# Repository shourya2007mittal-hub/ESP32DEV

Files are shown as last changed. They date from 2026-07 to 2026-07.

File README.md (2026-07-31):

# ESP32DEV



I made a custom Devboard based on ESP32-S3-WROOM-1 . It has voltage regulator , LED indicators , Boot Pin and the best part is that all the Pins available on the WROOM-1 is accessible via connector including BOOT, EN, DATA Lines.

## Features
- Base on  ESP32-S3-WROOM-1
- Has 3.3 V voltage regulator 
- All the possible WROOM-1 pins are accesible via pin connector

---

 | Top Designator | Comment | Footprint | Qty | Total Price (USD) | Product Link |
|:--------------|:--------|:----------|---:|------------------:|:-------------|
| C2 | 47uF | 0201 | 2 | $1.3330 | https://jlcpcb.com/partdetail/3127-KM476M450K25RR0VH2FP0/C2746 |
| C3 | 10uF | 0201 | 20 | $0.5860 | https://jlcpcb.com/partdetail/2043-CL10A106MQ8NNNC/C1691 |
| C4 | 100nF | 0201 | 20 | $0.1460 | https://jlcpcb.com/partdetail/MurataElectronics-GRM033R61A104KE15D/C76934 |
| C5, C6 | 22uF | 0201 | 8 | $2.5128 | https://jlcpcb.com/partdetail/2211-1206X226K100NT/C1859 |
| C5(1UF)1, C6(100NF)1 | C5(1UF)1, C6(100NF)1 | 0805 | 20 | $0.6440 | https://jlcpcb.com/partdetail/YAGEO-CC0805KRX7R9BB104/C49678 |
| D1, D2, D3 | LED | 0201 | 10 | $0.6810 | https://jlcpcb.com/partdetail/XINGLIGHT-XL0201SURC/C3646923 |
| D4 | 1N4001 | D_DO-41_SOD81_P2.54mm_Vertical_AnodeUp | 4 | $0.0776 | https://jlcpcb.com/partdetail/49200031-1N4001/C47018536 |
| L1 | 4.7uH | 0603 | 20 | $0.4140 | https://jlcpcb.com/partdetail/Sunlord-SDFL1608Q4R7KTF/C1034 |
| L2 | 2.2uH | 0603 | 20 | $0.5040 | https://jlcpcb.com/partdetail/270373-CMI160808U2R2KT/C284875 |
| Q1 | AO3401A | SOT-23 | 6 | $0.5946 | https://jlcpcb.com/partdetail/Alpha_OmegaSemicon-AO3401A/C15127 |
| R1, R2 | 33Ω | 0603 | 20 | $0.1580 | https://jlcpcb.com/partdetail/23867-0603WAF330JT5E/C23140 |
| R3, R4 | 50kΩ | 0603 | 20 | $0.6500 | https://jlcpcb.com/partdetail/YAGEO-RT0603BRD0750KL/C861451 |
| R6, R7, R8 | 1kΩ | 0201 | 20 | $0.0500 | https://jlcpcb.com/partdetail/259895-0201WMF1001TEE/C270365 |
| R1(10K)1, R2(100R)1 | R | 0805 | 6 | $0.5364 | https://jlcpcb.com/partdetail/FuzetecTech-FSMD050_0805R/C181350 |
| SW1, SW2 | Push Button | SW_SPST_PTS810 | 4 | $2.3948 | https://jlcpcb.com/partdetail/41719-DSHP02TSGET/C40735 |
| U5 | ESP32-S3-WROOM-1 | ESP32-S3-WROOM-1 | 2 | $10.8594 | https://jlcpcb.com/partdetail/3198300-ESP32_S3_WROOM_1N16R8/C2913202 |
| U2 | AP63203WU | TSOT-23-6 | 5 | $0.6019 | https://jlcpcb.com/partdetail/DiodesIncorporated-AP63203WU7/C780769 |
| PCB | PCB Fabrication | — | 1 | $4.00 | https://jlcpcb.com |
| SETUP | Assembly Setup Fee | — | 1 | $25.00 | https://jlcpcb.com |
| LOAD | Component Loading Fee | — | 1 | $14.00 | https://jlcpcb.com |
| SHIPPING | Shipping | — | 1 | $16.78 | https://jlcpcb.com |
| **TOTAL** | | | | **$82.5235** | https://jlcpcb.com |

### 💵 Cost Summary

| Item | Cost (USD) |
|---|---:|
| Components | $22.7435 |
| PCB Fabrication | $4.00 |
| Assembly Setup | $25.00 |
| Component Loading | $14.00 |
| Shipping | $16.78 |
| **Grand Total** | **$82.5235** |

### Schematic



###  PCB Design



### 3D Design



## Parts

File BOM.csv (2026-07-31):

Top Designator | Comment | Footprint | Quantity | Total Price | Product Link
C2 | 47uf | 0201 | 2.0 | 1.333 | https://jlcpcb.com/partdetail/3127-KM476M450K25RR0VH2FP0/C2746
C3 | 10uf | 0201 | 20.0 | 0.586 | https://jlcpcb.com/partdetail/2043-CL10A106MQ8NNNC/C1691
C4 | 100nf | 0201 | 20.0 | 0.146 | https://jlcpcb.com/partdetail/MurataElectronics-GRM033R61A104KE15D/C76934
C5,C6 | 22uf | 0201 | 8.0 | 2.5128 | https://jlcpcb.com/partdetail/2211-1206X226K100NT/C1859
C5(1UF)1,C6(100NF)1 | C5(1UF)1,C6(100NF)1 | 0805 | 20.0 | 0.644 | https://jlcpcb.com/partdetail/YAGEO-CC0805KRX7R9BB104/C49678
D1,D2,D3 | LED | 0201 | 10.0 | 0.681 | https://jlcpcb.com/partdetail/XINGLIGHT-XL0201SURC/C3646923
D4 | 1N4001 | D_DO-41_SOD81_P2.54mm_Vertical_AnodeUp | 4.0 | 0.0776 | https://jlcpcb.com/partdetail/49200031-1N4001/C47018536
L1 | 4.7uh | 0603 | 20.0 | 0.414 | https://jlcpcb.com/partdetail/Sunlord-SDFL1608Q4R7KTF/C1034
L2 | 2.2uh | 0603 | 20.0 | 0.504 | https://jlcpcb.com/partdetail/270373-CMI160808U2R2KT/C284875
Q1 | AO3401A | SOT-23 | 6.0 | 0.5946 | https://jlcpcb.com/partdetail/Alpha_OmegaSemicon-AO3401A/C15127
R1,R2 | 33R | 0603 | 20.0 | 0.158 | https://jlcpcb.com/partdetail/23867-0603WAF330JT5E/C23140
R3,R4 | 50K | 0603 | 20.0 | 0.65 | https://jlcpcb.com/partdetail/YAGEO-RT0603BRD0750KL/C861451
R6,R7,R8 | 1K | 0201 | 20.0 | 0.05 | https://jlcpcb.com/partdetail/259895-0201WMF1001TEE/C270365
R1(10K)1,R2(100R)1 | R | 0805 | 6.0 | 0.5364 | https://jlcpcb.com/partdetail/FuzetecTech-FSMD050_0805R/C181350
SW1,SW2 | SW_Push | SW_SPST_PTS810 | 4.0 | 2.3948 | https://jlcpcb.com/partdetail/41719-DSHP02TSGET/C40735
U5 | ESP32-S3-WROOM-1 | ESP32-S3-WROOM-1 | 2.0 | 10.8594 | https://jlcpcb.com/partdetail/3198300-ESP32_S3_WROOM_1N16R8/C2913202
U2 | AP63203WU | TSOT-23-6 | 5.0 | 0.6019 | https://jlcpcb.com/partdetail/DiodesIncorporated-AP63203WU7/C780769
PCB | PCB Cost |  | 1.0 | 4.0 | https://jlcpcb.com
SETUP | Setup Fee |  | 1.0 | 25.0 | https://jlcpcb.com
LOAD | Loading Fee |  | 1.0 | 14.0 | https://jlcpcb.com
SHIPPING | Shipping |  | 1.0 | 16.78 | https://jlcpcb.com
TOTAL |  |  |  | 82.5235 | https://jlcpcb.com

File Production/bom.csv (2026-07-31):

Designator | Footprint | Quantity | Value | LCSC Part #
C2 | 0201 | 1 | 47uf
C3 | 0201 | 1 | 10uf
C4 | 0201 | 1 | 100nf
C5, C6 | 0201 | 2 | 22uf
C5(1UF)1, C6(100NF)1 | 0805 | 2 | C
D1, D2, D3 | 0201 | 3 | LED
D4 | D_DO-41_SOD81_P2.54mm_Vertical_AnodeUp | 1 | 1N4001
F1 | 0201 | 1 | Polyfuse
J1 | USB_C_Receptacle_G-Switch_GT-USB-7010ASV | 1 | USB_C_Receptacle_USB2.0_16P
J2, J3 | PinHeader_1x18_P2.00mm_Vertical | 2 | Conn_01x18_Pin
J5 | PinHeader_1x04_P1.00mm_Vertical | 1 | Conn_01x04_Pin
J6 | AMASS_XT30U-F_1x02_P5.0mm_Vertical | 1 | Conn_01x02_Pin
L1 | 0603 | 1 | 4.7uh
L2 | 0603 | 1 | 2.2uh
Q1 | SOT-23 | 1 | AO3401A
R1, R2 | 0603 | 2 | 33 R
R1(10K)1, R2(100R)1 | 0805 | 2 | R
R3, R4 | 0603 | 2 | 50K
R6, R7, R8 | 0201 | 3 | 1K
SW1, SW2 | SW_SPST_PTS810 | 2 | SW_Push
U2 | TSOT-23-6 | 1 | AP63203WU
U5 | ESP32-S3-WROOM-1 | 1 | ESP32-S3-WROOM-1

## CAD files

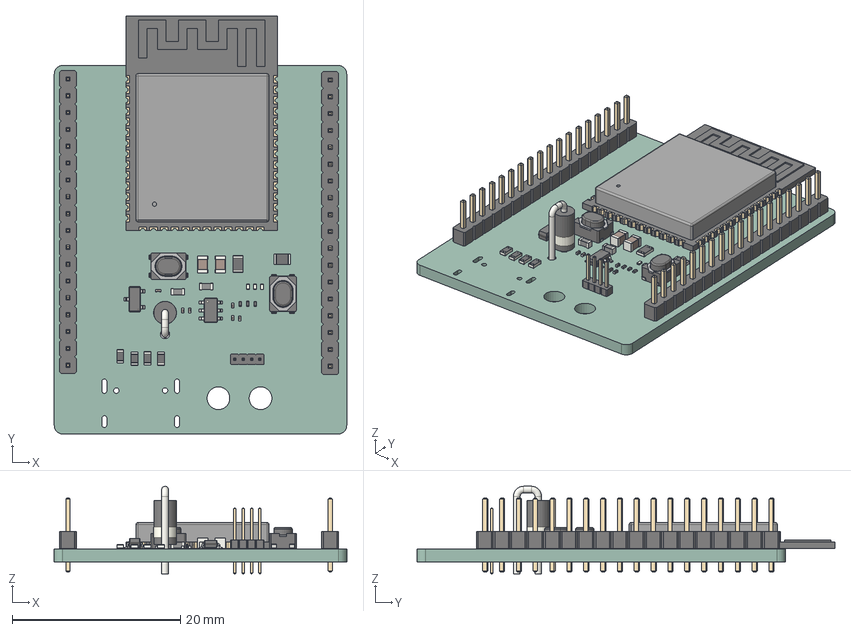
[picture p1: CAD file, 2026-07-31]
CAD/ESP32DEV.step
34.7 x 49.6 x 10.4 mm
C_0805_2012Metric x 2
PinHeader_1x18_P2.00mm_Vertical x 2
R_0805_2012Metric x 2
R_0201_0603Metric x 3
C_0201_0603Metric x 6
R_0603_1608Metric x 4
TSOT-23-6
SOT-23
SW_SPST_PTS810 x 2
LED_0201_0603Metric x 3
ESP32-S3-WROOM-1
D_DO-41_SOD81_P2.54mm_Vertical_AnodeUp
PinHeader_1x04_P1.00mm_Vertical
L_0603_1608Metric x 2
ESP32DEV_PCB

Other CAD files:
CAD/ESP32DEV.f3d

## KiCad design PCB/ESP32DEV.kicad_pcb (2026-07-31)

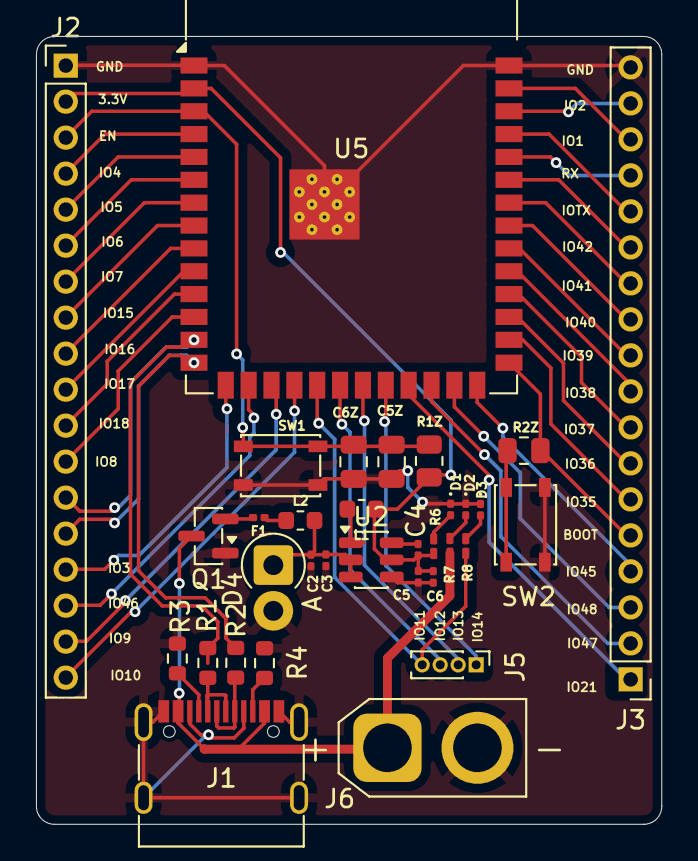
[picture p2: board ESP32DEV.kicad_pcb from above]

Board: 2 copper layers, 34.7 x 43.8 mm, 33 parts (0 on the bottom side), 53 nets.

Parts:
C2: 47uf; C_0201_0603Metric
C3: 10uf; C_0201_0603Metric
C4: 100nf; C_0201_0603Metric
C5, C6: 22uf; C_0201_0603Metric
C5Z, C6Z: C; C_0805_2012Metric
D1, D2, D3: LED; LED_0201_0603Metric
D4: 1N4001; D_DO-41_SOD81_P2.54mm_Vertical_AnodeUp
F1: Polyfuse; C_0201_0603Metric
J1: USB_C_Receptacle_USB2.0_16P; USB_C_Receptacle_G-Switch_GT-USB-7010ASV
J2, J3: Conn_01x18_Pin; PinHeader_1x18_P2.00mm_Vertical
J5: Conn_01x04_Pin; PinHeader_1x04_P1.00mm_Vertical
J6: Conn_01x02_Pin; AMASS_XT30U-F_1x02_P5.0mm_Vertical
L1: 4.7uh; L_0603_1608Metric
L2: 2.2uh; L_0603_1608Metric
Q1: AO3401A; SOT-23
R1, R2: 33 R; R_0603_1608Metric
R1Z, R2Z: R; R_0805_2012Metric
R3, R4: 50K; R_0603_1608Metric
R6, R7, R8: 1K; R_0201_0603Metric_Pad0.64x0.40mm_HandSolder
SW1, SW2: SW_Push; SW_SPST_PTS810
U2: AP63203WU; TSOT-23-6
U5: ESP32-S3-WROOM-1

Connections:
+3.3V: C4.1, C5.1, C6.1, J2.2, L1.1, R1Z.1, R6.1, U2.5 (SW), U5.2 (3V3)
+5V: J1.A4 (VBUS), J1.A9 (VBUS), J1.B4 (VBUS), J1.B9 (VBUS), J6.1, Q1.3 (D), R7.2
BOOT: J3.5, R2Z.1, U5.27 (IO0)
EN: C5Z.1, C6Z.1, J2.3, R1Z.2, SW1.1, U5.3 (EN)
GND: C2.2, C3.2, C5.2, C5Z.2, C6.2, C6Z.2, D1.1 (K), D2.1 (K), D3.1 (K), D4.2 (A), J1.A1 (GND), J1.A8 (SBU1), J1.A12 (GND), J1.B1 (GND), J1.B8 (SBU2), J1.B12 (GND), J1.S1 (SHIELD), J2.1, J3.18, J6.2, Q1.1 (G), R3.2, R4.2, SW1.2, SW2.2, U2.4 (GND), U5.1 (GND), U5.40 (GND), U5.41 (GND)
I01: J3.16, U5.39 (IO1)
I02: J3.17, U5.38 (IO2)
I03: J2.15, U5.15 (IO3)
I04: J2.4, U5.4 (IO4)
I05: J2.5, U5.5 (IO5)
I06: J2.6, U5.6 (IO6)
I07: J2.7, U5.7 (IO7)
I08: J2.12, U5.12 (IO8)
I09: J2.17, U5.17 (IO9)
I010: J2.18, U5.18 (IO10)
I011: J5.4, R8.2, U5.19 (IO11)
I012: J5.3, U5.20 (IO12)
I013: J5.2, U5.21 (IO13)
I014: J5.1, U5.22 (IO14)
I015: J2.8, U5.8 (IO15)
I016: J2.9, U5.9 (IO16)
I017: J2.10, U5.10 (IO17)
I018: J2.11, U5.11 (IO18)
I021: J3.1, U5.23 (IO21)
I035: J3.6, U5.28 (IO35)
I036: J3.7, U5.29 (IO36)
I037: J3.8, U5.30 (IO37)
I038: J3.9, U5.31 (IO38)
I039: J3.10, U5.32 (IO39)
I040: J3.11, U5.33 (IO40)
I041: J3.12, U5.34 (IO41)
I042: J3.13, U5.35 (IO42)
I045: J3.4, U5.26 (IO45)
I046: J2.16, U5.16 (IO46)
I047: J3.2, U5.24 (IO47)
I048: J3.3, U5.25 (IO48)
unnamed: D1.2 (A), R6.2
unnamed: D2.2 (A), R7.1
unnamed: D3.2 (A), R8.1
unnamed: C2.1, C3.1, D4.1 (K), L2.2, U2.2 (EN), U2.3 (IN)
unnamed: F1.2, L2.1
unnamed: J1.A5 (CC1), R3.1
unnamed: J1.B5 (CC2), R4.1
unnamed: J1.A6 (D+), J1.B6 (D+), R2.1
unnamed: J1.A7 (D-), J1.B7 (D-), R1.1
unnamed: F1.1, Q1.2 (S)
unnamed: R2Z.2, SW2.1
unnamed: C4.2, U2.6 (BST)
unnamed: L1.2, U2.1 (FB)
RX: J3.15, U5.36 (RXD0)
TX: J3.14, U5.37 (TXD0)
_D+: J2.14, R2.2, U5.14 (USB_D+)
_D-: J2.13, R1.2, U5.13 (USB_D-)
